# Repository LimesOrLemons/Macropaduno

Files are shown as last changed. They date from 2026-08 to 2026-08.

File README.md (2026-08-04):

# Macropaduno

An ESP32-S3 handheld controller with a custom PCB and 3D-printed enclosure for numerous programmable functions.

## Overview

Welcome to **Macropaduno**, a custom-designed handheld controller powered by an ESP32-S3. This is the second iteration of the design, significantly expanded to pack maximum functionality into a compact layout for advanced programming and testing.



## Features & Hardware Specs

* **Microcontroller:** ESP32-S3
* **Connectivity:** Bluetooth & Wi-Fi
* **Power Management:** Integrated battery management, internal power system, and a voltage booster (3.3V to 5V)
* **Audio:** Onboard speaker driven by an audio amplifier
* **Visuals:** OLED screen, camera module (OV2640), and addressable RGB LED
* **Input Controls:**
* 9x Mechanical key switches
* 2x Pressable joysticks
* 1x Pressable rotary encoder switch

* **Expansion:** Dedicated servo/header port for external peripherals and motors

## Project Journey & Lessons Learned

This design represents about a month of intensive work on the digital and schematic design side. Moving from a much smaller initial prototype, this version integrates all peripheral components onto a single custom PCB paired with a 3D-printed enclosure.

While the form factor turned out a bit bulkier than originally planned, it serves as an exceptional foundation for future iterations. Key engineering takeaways from this project include:

* Introduction to KiCad schematic and PCB layout & practices
* C++ firmware development for the ESP32-S3 and electronic components
* Planning for acoustic chambers, battery integration, and mechanical clearance in 3D CAD (modeled in Onshape, with future plans to explore SolidWorks for professional CAD workflows).
* Identifying areas for future optimization, such as transitioning to 4-layer boards and component stacking for tighter spatial efficiency.



## Version 1 Prototype
Here is what the v1 version of the macropad looked like:



## Version 2 Prototype
Here is what the v2 version of the macropad looked like:



## Acknowledgements & Credits

Special thanks to the open-source community and creators who shared CAD models and reference files used during the design process:

* [603040 600mAh LiPo Battery Cell on GrabCAD](https://grabcad.com/library/603040-600mah-lipo-battery-cell-1)
* [Cherry MX Switches on GrabCAD](https://grabcad.com/library/cherry-mx-switches-mx-1)
* [OV2640 Camera Model on GrabCAD](https://grabcad.com/library/ov2640-for-esp32-cam-1)
* [JST PH 2.0mm Connector Pack on GrabCAD](https://grabcad.com/library/jst-ph-2-0mm-connector-pack-through-hole-smt-ds1066-1)
* [Rotary Encoder on GrabCAD](https://grabcad.com/library/rotary-encoder-17)
* [0.91" OLED 128x32 Display on GrabCAD](https://grabcad.com/library/oled-0-91-128x32-1)
* [CherryMX GitHub Library by hineybush](https://github.com/hineybush/CherryMX/tree/master)

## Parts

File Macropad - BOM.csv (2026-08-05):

Link | Part Name | Quantity | Unit Cost | Total Cost | Desc.
https://www.digikey.com/en/products/detail/seeed-technology-co-ltd/102010671/26553873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 | ESP32 S3 Plus | 1 | $7.90 | $7.90 | MCU
https://www.digikey.com/en/products/detail/microchip-technology/MCP23017-E-SO/894271 | MCP23017 | 1 | $1.62 | $1.62 | I/O Expand
https://www.digikey.com/en/products/detail/cherry-americas-llc/MX1A-C1NW/280855 | MX1A-C1NW | 9 | $1.25 | $11.25 | Cherry Switch
https://www.digikey.com/en/products/detail/sparkfun-electronics/09032/6823623?s=N4IgTCBcDaIAwE44GYIF0C%2BQ | COM-9032 | 2 | $5.25 | $10.50 | Joystick
https://www.digikey.com/en/products/detail/bourns-inc/PEC11R-4220F-S0024/4499660 | PEC11R-4220F-S0024 | 1 | $2.69 | $2.69 | Rotary
https://www.amazon.com/AITRIP-Display-Self-Luminous-Compatible-Raspberry/dp/B0F5WPZJ92 | .96 In OLED | 1 | $11.99 | $11.99 | OLED
https://www.amazon.com/MAX98357-MAX98357A-Amplifier-Interface-Raspberry/dp/B0DPJRLMDJ | MAX98357A | 1 | $6.88 | $6.88 | Audio Amp
https://www.digikey.com/en/products/detail/same-sky-formerly-cui-devices/CVS-1508/2791828 | CVS-1508 | 1 | $3.95 | $3.95 | Speaker
https://www.adafruit.com/product/1655 | WS2812B | 1 | $4.50 | $4.50 | SMT LED
https://www.digikey.com/en/products/detail/texas-instruments/LP5907MFX-2-8-NOPB/3906436 | LP5907MFX-2.8/NOPB | 2 | $0.62 | $1.24 | LDO 2.8V
https://www.digikey.com/en/products/detail/microchip-technology/MIC5365-1-3YC5-TR/1868078 | MIC5365-1.3YC5-TR | 1 | $0.12 | $0.12 | LDO 1.3V
https://www.amazon.com/OV5640-Camera-120%C2%B0Autofocus-Megapixel-Computer/dp/B0FVRJG44N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 | OV5640 | 1 | $24.99 | $24.99 | CAM
https://www.digikey.com/en/products/detail/aces-connectors/50696-0240M-002/21623832 | 50696-0240M-002 | 1 | $0.53 | $0.53 | 24 pin FPC
https://www.digikey.com/en/products/detail/olimex-ltd/SMD-IC-MT3608/29208971?s=N4IgTCBcDaILYBcDMA2ADADhAXQL5A | MT3608 | 10 | $0.32 | $3.16 | Volt Booster
https://www.digikey.com/en/products/detail/jst-sales-america-inc/B2B-PH-SM4-TB/926641 | B2B-PH-SM4-TB | 1 | $0.47 | $0.47 | JST for Batt
https://www.amazon.com/QSYZAIL-Connector-Compatible-Arduino-Prototyping/dp/B0G578NSXC?s=hi | Header Pins | 1 | $9.99 | $9.99 | Header Pins
https://www.digikey.com/en/products/detail/onsemi/1N4148/458603 | Diode | 1 | $0.60 | $0.60 | For Matrix
https://www.digikey.com/en/products/detail/vishay-beyschlag-draloric-bc-components/K104K15X7RF5TH5/286555 | K104K15X7RF5TH5 | 1 | $1.67 | $1.67 | 0.1uf cap
https://www.digikey.com/en/products/detail/murata-electronics/RDEC71H226MWK1H03B/7362914 | RDEC71H226MWK1H03B | 1 | $1.75 | $1.75 | 22uf cap
https://www.digikey.com/en/products/detail/rubycon/50YXJ22MTA5X11/3134939 | 50YXJ22MTA5X11 | 2 | $0.23 | $0.46 | 22uf pol cap
https://www.digikey.com/en/products/detail/bourns-inc/RLB0914-150KL/2561356 | RLB0914-150KL | 1 | $0.38 | $0.38 | 15uH inductor
https://www.digikey.com/en/products/detail/tdk/FG28X7R1E105KRT06/5803197 | FG28X7R1E105KRT06 | 1 | $1.93 | $1.93 | 1uf cap for LDO
https://www.digikey.com/en/products/detail/vishay-general-semiconductor-diodes-division/SB240S-E3-54/2146197 | SB240S-E3/54 | 1 | $0.67 | $0.67 | Schottky Diode
https://www.digikey.com/en/products/detail/stackpole-electronics-inc/CF14JT4K70/1741428 | CF14JT4K70 | 1 | $0.27 | $0.27 | 4.7kohm r
https://www.digikey.com/en/products/detail/yageo/MFR-25FBF52-10K2/13221 | MFR-25FBF52-10K2 | 1 | $0.42 | $0.42 | 10.2kohm r
https://www.digikey.com/en/products/detail/stackpole-electronics-inc/CF14JT75K0/1741505 | CF14JT75K0 | 1 | $0.57 | $0.57 | 75kohm r
https://trade.jlcpcb.com/checkout/payMethod/?unionSettleId=6abc479397ef40caa6771d3a5667d1ee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 | Board Fab | 1 | $2.00 | $2.00 | JLCPCB
 | Shipping | 1 | $20.00 | $20.00 | shipping est.
 | Total |  |  | $132.50

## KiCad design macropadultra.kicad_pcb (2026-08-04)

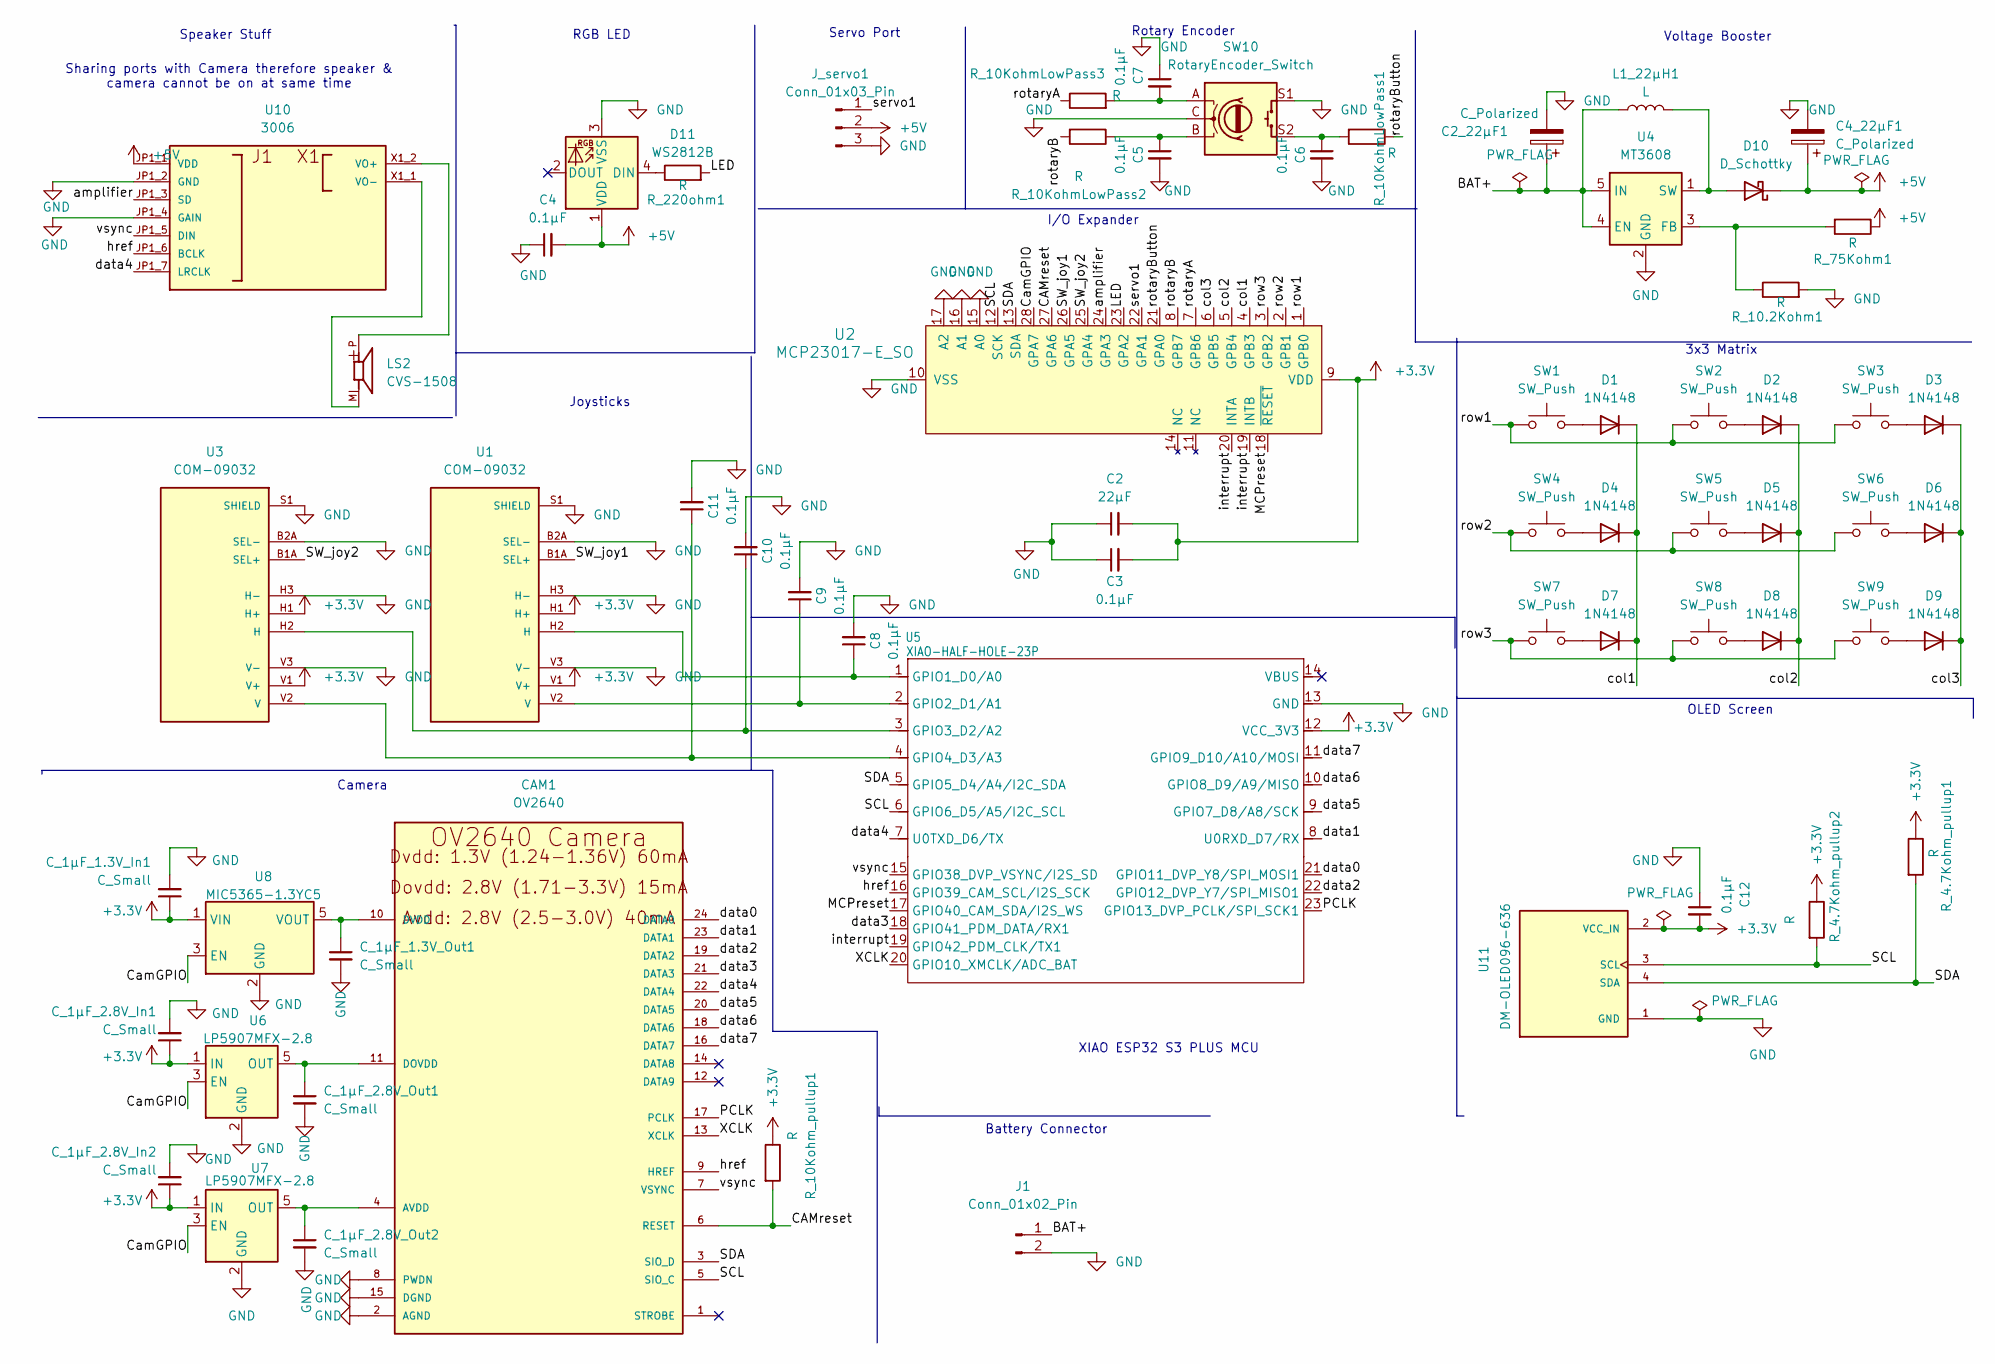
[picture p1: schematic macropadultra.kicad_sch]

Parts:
C2: 22µF; C_Disc_D5.0mm_W2.5mm_P5.00mm
C2_22µF1, C4_22µF1: C_Polarized; CP_Radial_D5.0mm_P2.00mm
C3, C4, C5, C6, C7, C8, C9, C10, C11, C12: 0.1µF; C_Disc_D5.0mm_W2.5mm_P5.00mm
CAM1: OV2640
C_1µF_1.3V_In1, C_1µF_1.3V_Out1, C_1µF_2.8V_In1, C_1µF_2.8V_In2, C_1µF_2.8V_Out1, C_1µF_2.8V_Out2: C_Small; C_Disc_D5.0mm_W2.5mm_P5.00mm
D1, D2, D3, D4, D5, D6, D7, D8, D9: 1N4148; D_DO-35_SOD27_P7.62mm_Horizontal
D10: D_Schottky; D_DO-41_SOD81_P10.16mm_Horizontal
D11: WS2812B; LED_WS2812B_PLCC4_5.0x5.0mm_P3.2mm
J1: Conn_01x02_Pin; JST_PH_S2B-PH-SM4-TB_1x02-1MP_P2.00mm_Horizontal
J_servo1: Conn_01x03_Pin; PinHeader_1x03_P2.54mm_Horizontal
L1_22µH1: L; L_Radial_D10.0mm_P5.00mm_Fastron_07M
LS2: CVS-1508; SPKR_CVS-1508
R_4.7Kohm_pullup1, R_4.7Kohm_pullup2, R_10.2Kohm1, R_10KohmLowPass1, R_10KohmLowPass2, R_10KohmLowPass3, R_10Kohm_pullup1, R_75Kohm1, R_220ohm1: R; R_Axial_DIN0207_L6.3mm_D2.5mm_P10.16mm_Horizontal
SW1, SW2, SW3, SW4, SW5, SW6, SW7, SW8, SW9: SW_Push; SW_Cherry_MX_1.00u_PCB
SW10: RotaryEncoder_Switch; RotaryEncoder_Alps_EC11E-Switch_Vertical_H20mm
U1, U3: COM-09032; XDCR_COM-09032; PARTREV N/A
U2: MCP23017-E_SO; SOIC-28_W7.5mm; MPN MCP23017-E/SO; Digi-Key_PN MCP23017-E/SO-ND
U4: MT3608; SOT-23-6
U5: XIAO-HALF-HOLE-23P; XIAO-ESP32-S3-Plus-SMD
U6, U7: LP5907MFX-2.8; SOT-23-5
U8: MIC5365-1.3YC5; SOT-353_SC-70-5
U10: 3006; MODULE_3006; PARTREV A
U11: DM-OLED096-636; MODULE_DM-OLED096-636; PARTREV 2018-09-10

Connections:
+3.3V: C2.2, C3.2, C12.2, C_1µF_1.3V_In1.1, C_1µF_2.8V_In1.1, C_1µF_2.8V_In2.1, R_4.7Kohm_pullup1.1, R_4.7Kohm_pullup2.1, R_10Kohm_pullup1.1, U1.H1 (H+), U1.V1 (V+), U2.9 (VDD), U3.H1 (H+), U3.V1 (V+), U5.12 (VCC_3V3), U6.1 (IN), U7.1 (IN), U8.1 (VIN), U11.2 (VCC_IN)
+5V: C4.2, C4_22µF1.1, D10.1 (K), D11.1 (VDD), J_servo1.2, R_75Kohm1.1, U10.JP1_1 (VDD)
/BAT+: C2_22µF1.1, J1.1, L1_22µH1.1, U4.4 (EN), U4.5 (IN), U5.32
/CAMreset: CAM1.6 (RESET), R_10Kohm_pullup1.2, U2.27 (GPA6)
/CamGPIO: U2.28 (GPA7), U6.3 (EN), U7.3 (EN), U8.3 (EN)
/LED: R_220ohm1.2, U2.23 (GPA2)
/MCPreset: U2.18 (~RESET), U5.17 (GPIO40_CAM_SDA/I2S_WS)
/PCLK: CAM1.17 (PCLK), U5.23 (GPIO13_DVP_PCLK/SPI_SCK1)
/SCL: CAM1.5 (SIO_C), R_4.7Kohm_pullup2.2, U2.12 (SCK), U5.6 (GPIO6_D5/A5/I2C_SCL), U11.3 (SCL)
/SDA: CAM1.3 (SIO_D), R_4.7Kohm_pullup1.2, U2.13 (SDA), U5.5 (GPIO5_D4/A4/I2C_SDA), U11.4 (SDA)
/SW_joy1: U1.B1A (SEL+), U2.26 (GPA5)
/SW_joy2: U2.25 (GPA4), U3.B1A (SEL+)
/XCLK: CAM1.13 (XCLK), U5.20 (GPIO10_XMCLK/ADC_BAT)
/amplifier: U2.24 (GPA3), U10.JP1_3 (SD)
/col1: D1.1 (K), D4.1 (K), D7.1 (K), U2.4 (GPB3)
/col2: D2.1 (K), D5.1 (K), D8.1 (K), U2.5 (GPB4)
/col3: D3.1 (K), D6.1 (K), D9.1 (K), U2.6 (GPB5)
/data0: CAM1.24 (DATA0), U5.21 (GPIO11_DVP_Y8/SPI_MOSI1)
/data1: CAM1.23 (DATA1), U5.8 (U0RXD_D7/RX)
/data2: CAM1.19 (DATA2), U5.22 (GPIO12_DVP_Y7/SPI_MISO1)
/data3: CAM1.21 (DATA3), U5.18 (GPIO41_PDM_DATA/RX1)
/data4: CAM1.22 (DATA4), U5.7 (U0TXD_D6/TX), U10.JP1_7 (LRCLK)
/data5: CAM1.20 (DATA5), U5.9 (GPIO7_D8/A8/SCK)
/data6: CAM1.18 (DATA6), U5.10 (GPIO8_D9/A9/MISO)
/data7: CAM1.16 (DATA7), U5.11 (GPIO9_D10/A10/MOSI)
/href: CAM1.9 (HREF), U5.16 (GPIO39_CAM_SCL/I2S_SCK), U10.JP1_6 (BCLK)
/interrupt: U2.19 (INTB), U2.20 (INTA), U5.19 (GPIO42_PDM_CLK/TX1)
/rotaryA: R_10KohmLowPass3.1, U2.7 (GPB6)
/rotaryB: R_10KohmLowPass2.2, U2.8 (GPB7)
/rotaryButton: R_10KohmLowPass1.1, U2.21 (GPA0)
/row1: SW1.1, SW2.1, SW3.1, U2.1 (GPB0)
/row2: SW4.1, SW5.1, SW6.1, U2.2 (GPB1)
/row3: SW7.1, SW8.1, SW9.1, U2.3 (GPB2)
/servo1: J_servo1.1, U2.22 (GPA1)
/vsync: CAM1.7 (VSYNC), U5.15 (GPIO38_DVP_VSYNC/I2S_SD), U10.JP1_5 (DIN)
GND: C2.1, C2_22µF1.2, C3.1, C4.1, C4_22µF1.2, C5.2, C6.2, C7.1, C8.2, C9.2, C10.2, C11.2, C12.1, CAM1.2 (AGND), CAM1.8 (PWDN), CAM1.15 (DGND), CAM1.MT1 (DGND), CAM1.MT2 (DGND), C_1µF_1.3V_In1.2, C_1µF_1.3V_Out1.2, C_1µF_2.8V_In1.2, C_1µF_2.8V_In2.2, C_1µF_2.8V_Out1.2, C_1µF_2.8V_Out2.2, D11.3 (VSS), J1.2, J_servo1.3, R_10.2Kohm1.2, SW10.C, SW10.S1, U1.B2A (SEL-), U1.H3 (H-), U1.S1 (SHIELD), U1.S2 (SHIELD), U1.S3 (SHIELD), U1.S4 (SHIELD), U1.V3 (V-), U2.10 (VSS), U2.15 (A0), U2.16 (A1), U2.17 (A2), U3.B2A (SEL-), U3.H3 (H-), U3.S1 (SHIELD), U3.S2 (SHIELD), U3.S3 (SHIELD), U3.S4 (SHIELD), U3.V3 (V-), U4.2 (GND), U5.13 (GND), U5.33, U6.2 (GND), U7.2 (GND), U8.2 (GND), U10.JP1_2 (GND), U10.JP1_4 (GAIN), U11.1 (GND)
unnamed: C5.1, R_10KohmLowPass2.1, SW10.B
unnamed: C6.1, R_10KohmLowPass1.2, SW10.S2
unnamed: C7.2, R_10KohmLowPass3.2, SW10.A
unnamed: CAM1.4 (AVDD), C_1µF_2.8V_Out2.1, U7.5 (OUT)
unnamed: CAM1.11 (DOVDD), C_1µF_2.8V_Out1.1, U6.5 (OUT)
unnamed: CAM1.10 (DVDD), C_1µF_1.3V_Out1.1, U8.5 (VOUT)
unnamed: D1.2 (A), SW1.2
unnamed: D2.2 (A), SW2.2
unnamed: D3.2 (A), SW3.2
unnamed: D4.2 (A), SW4.2
unnamed: D5.2 (A), SW5.2
unnamed: D6.2 (A), SW6.2
unnamed: D7.2 (A), SW7.2
unnamed: D8.2 (A), SW8.2
unnamed: D9.2 (A), SW9.2
unnamed: D10.2 (A), L1_22µH1.2, U4.1 (SW)
unnamed: D11.4 (DIN), R_220ohm1.1
unnamed: C8.1, U1.H2 (H), U5.1 (GPIO1_D0/A0)
unnamed: C9.1, U1.V2 (V), U5.2 (GPIO2_D1/A1)
unnamed: C10.1, U3.H2 (H), U5.3 (GPIO3_D2/A2)
unnamed: C11.1, U3.V2 (V), U5.4 (GPIO4_D3/A3)
unnamed: R_10.2Kohm1.1, R_75Kohm1.2, U4.3 (FB)
unnamed: LS2.P, U10.X1_2 (VO+)
unnamed: LS2.M, U10.X1_1 (VO-)

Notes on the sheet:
Joysticks
Voltage Booster
Battery Connector
Rotary Encoder
Camera
3x3 Matrix
OLED Screen
Sharing ports with Camera therefore speaker & camera cannot be on at same time
I/O Expander
RGB LED
Speaker Stuff
XIAO ESP32 S3 PLUS MCU
Servo Port

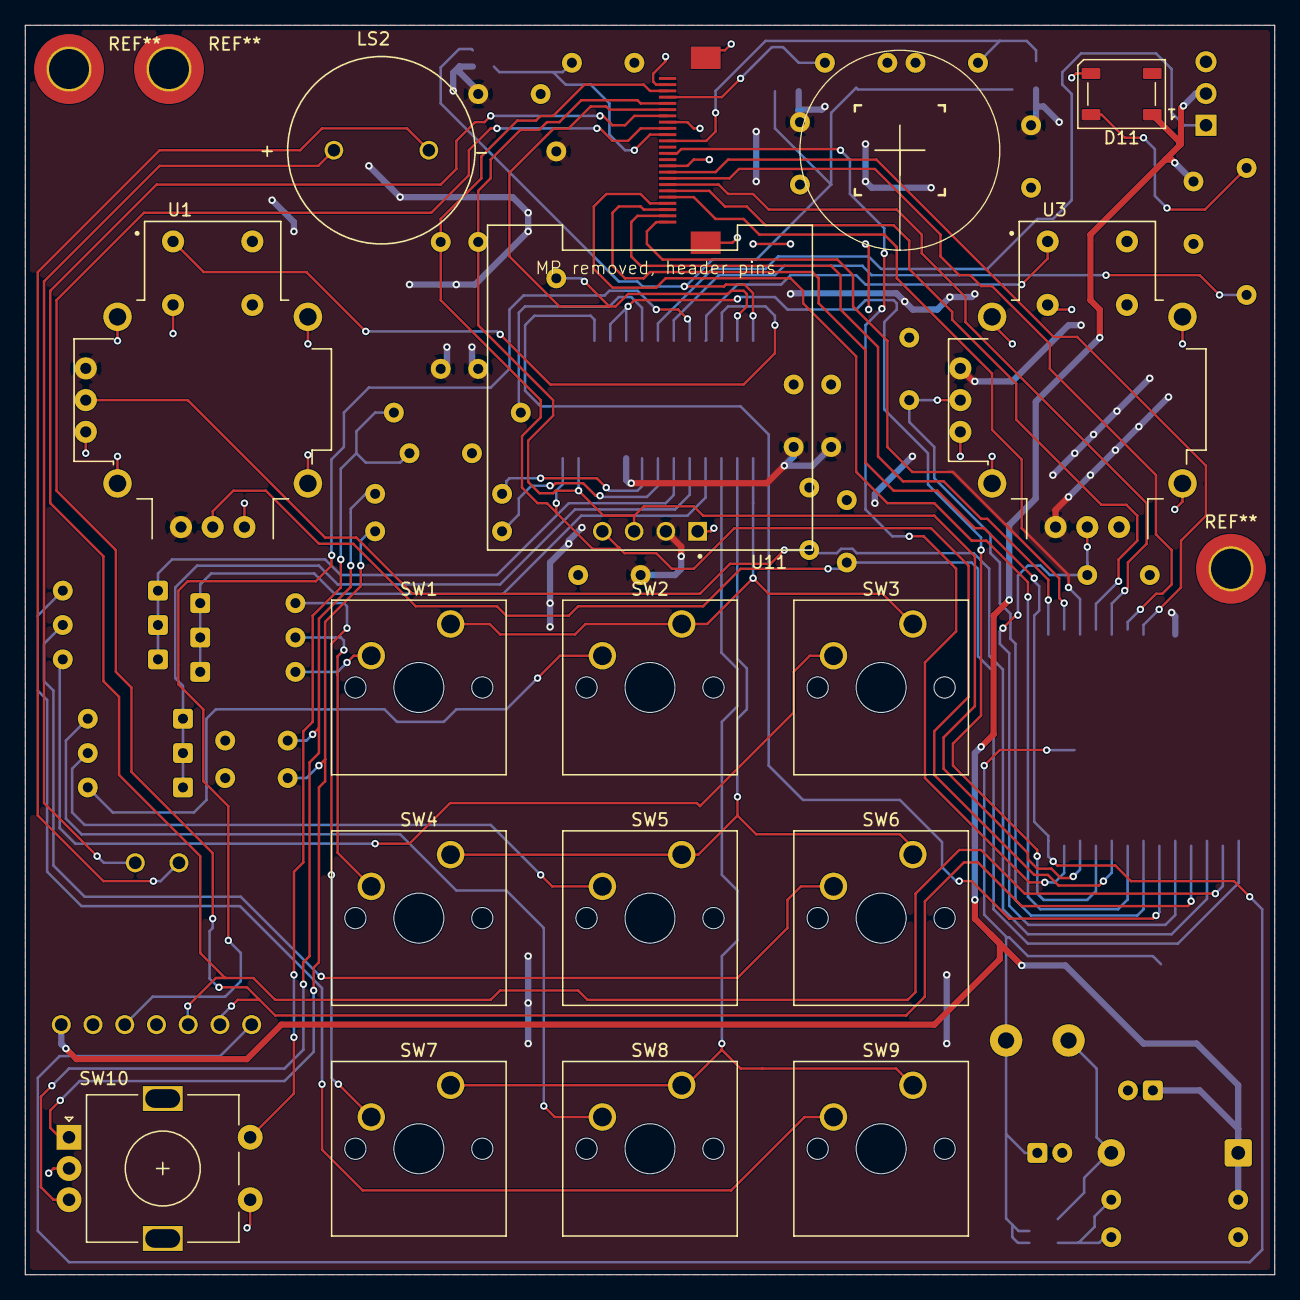
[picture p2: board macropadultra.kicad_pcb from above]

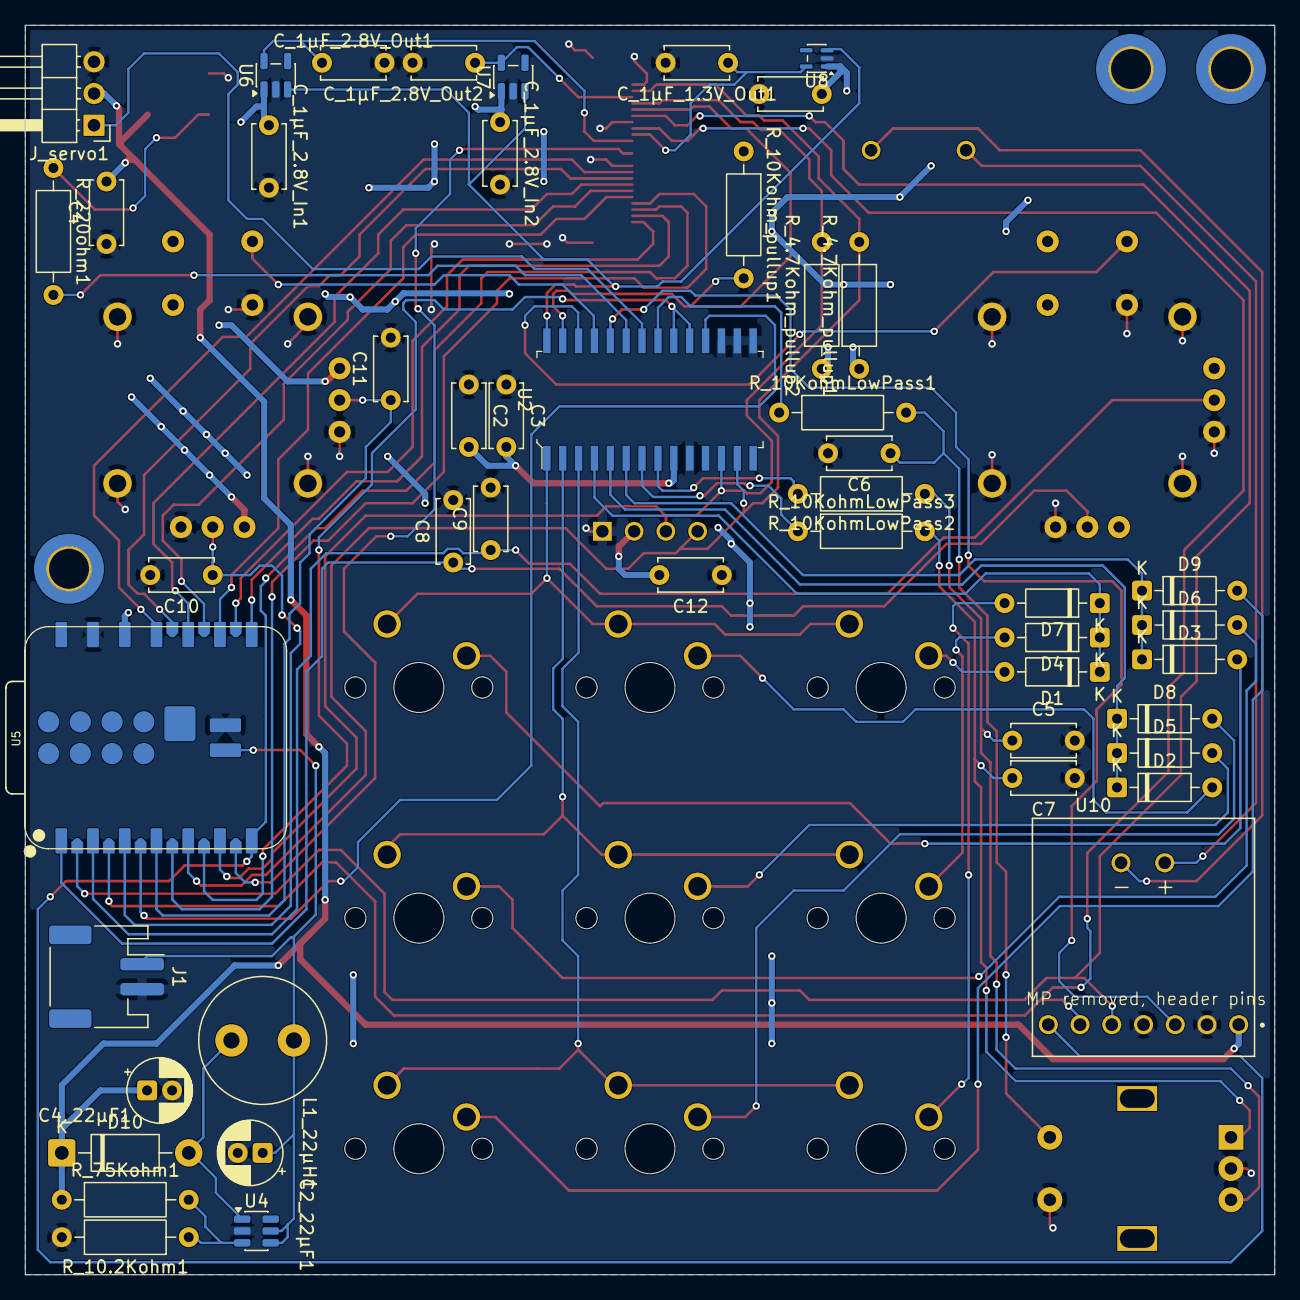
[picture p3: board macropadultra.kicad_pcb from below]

Board: 2 copper layers, 100.0 x 100.0 mm, 64 parts (48 on the bottom side), 60 nets.

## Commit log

2026-07-25 Update .gitignore
    Update .gitignore to include CLion, CMake, and Arduino build excludes
2026-07-25 Add files via upload
    Uploaded STEP files for board, case, and both and also the KICAD project.
    [microcontrollersuper.kicad_pcb, microcontrollersuper.kicad_sch]
